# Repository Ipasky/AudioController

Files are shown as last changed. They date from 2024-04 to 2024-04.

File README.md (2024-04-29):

# Physical Audio Controller | Deej
This is my own 3D printing design that implements Deej software https://github.com/omriharel/deej able to control audio and mic devices on your computer in a physical way.

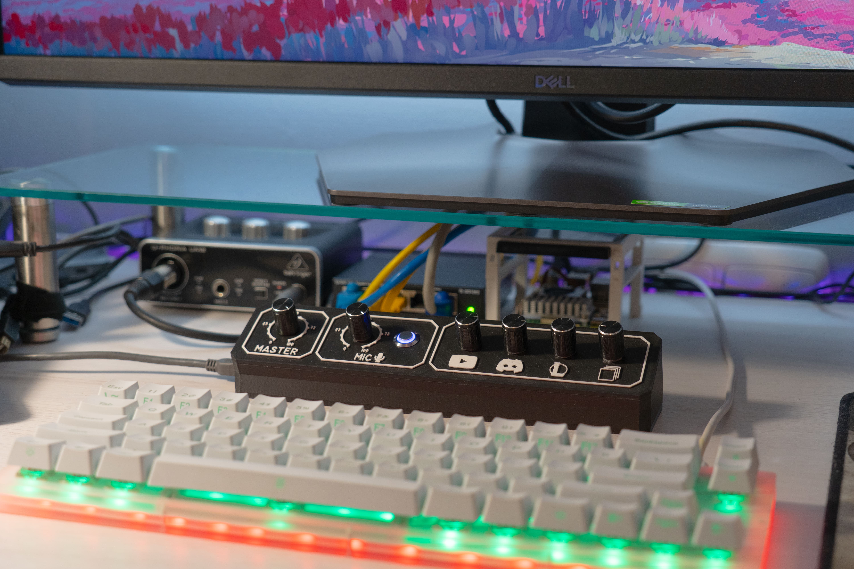
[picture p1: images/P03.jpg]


| | |
|:---:|:---:|
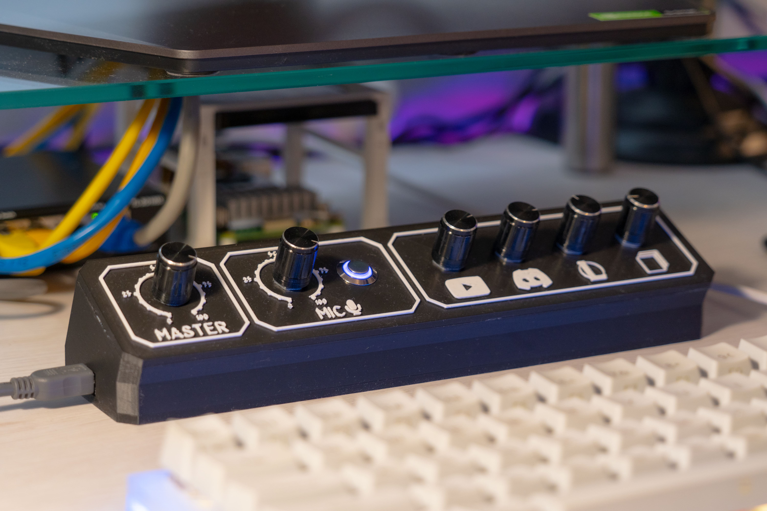
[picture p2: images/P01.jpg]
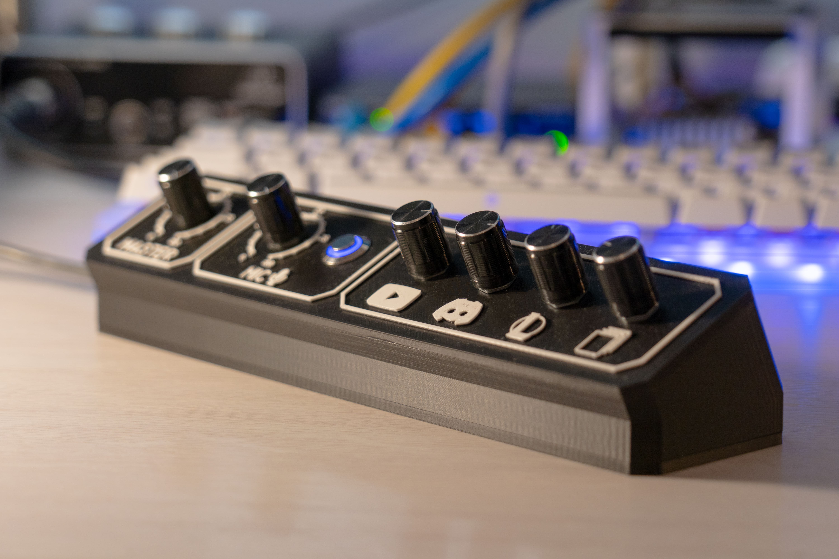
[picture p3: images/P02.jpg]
|  |  |

## Description
The build implements an Arduino Nano that carry the default code from Deej, in my case, with some modifications because I use a LED push button. You can found my modified code here: [Arduino Code](https://github.com/Ipasky/AudioControllerDeej/blob/main/DeejArduinoCodeMod.ino)

This additional code, in a nutshell, contains more analog inputs and one digital output (for the LED). Because the push button is not auto locking, that means the button is just pressed while you're pushing, in the Arduino code I need to implement a digital variable that controls the pulsation, writing in COM port and turning on and off the LED. I found the code from this page: https://roboticsbackend.com/arduino-turn-led-on-and-off-with-button/

I let here a schematic about the wiring, be aware that in this pic the Arduino board is not a Nano ones, for that reason it doesn't have 8 analogic ports.

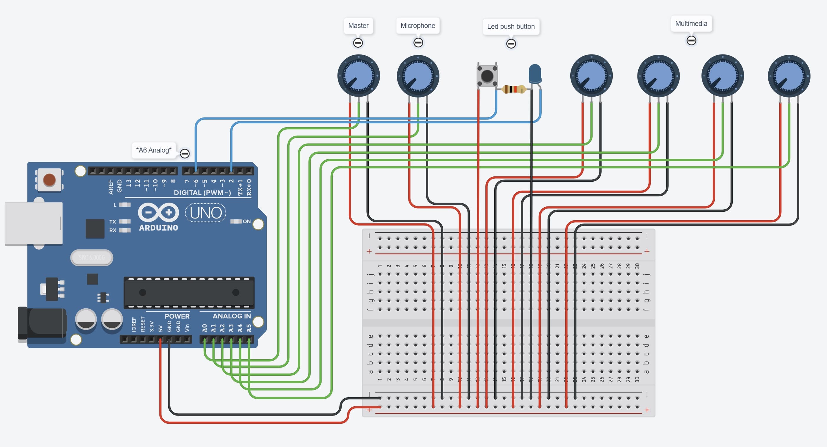
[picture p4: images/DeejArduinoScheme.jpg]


The push button that I use have 4 pins, two of them to the push button itself, and two more for the LED. In my case, I need to add a resistance trough negative LED pin to analog button pin. I really don't know if this wiring is the optimum, but it works for me.
| | |
|:---:|:---:|
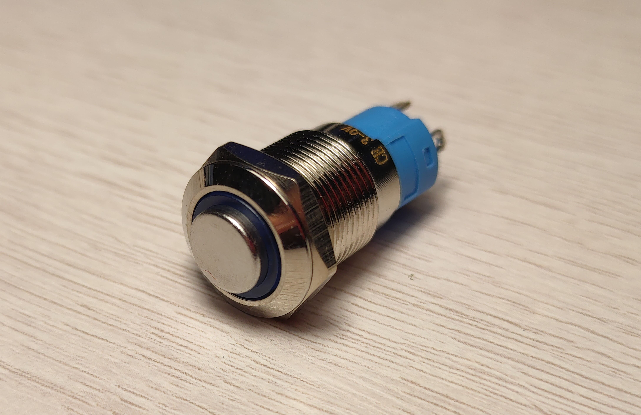
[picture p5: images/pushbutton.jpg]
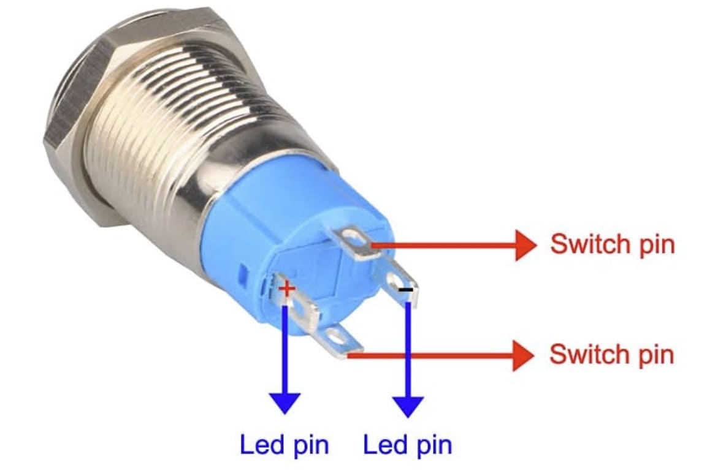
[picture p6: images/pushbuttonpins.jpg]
|  |  |

The final wiring looks like this:

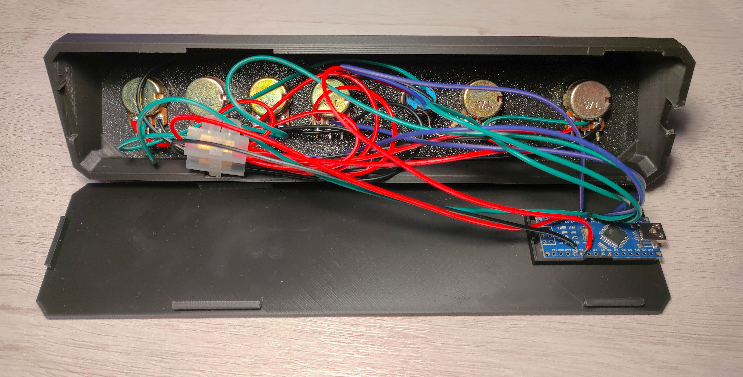
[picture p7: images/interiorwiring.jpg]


## Specs
- Dimensions: 220 x 60 x 44 mm
- Weight: 170g
- Material: black PLA & white PLA
- Printing time: 13h 44min

## Components
- [Arduino Nano](https://www.amazon.es/dp/B078S8BJ8T?psc=1&ref=ppx_yo2ov_dt_b_product_details) 
- [Potentiometers Kit](https://www.amazon.es/gp/product/B087Q9JVYD/ref=ppx_yo_dt_b_asin_title_o03_s01?ie=UTF8&psc=1)
- [Knobs](https://www.amazon.es/gp/product/B07DNBDFW8/ref=ppx_yo_dt_b_asin_title_o03_s00?ie=UTF8&psc=1)
- [Push Button](https://www.amazon.es/dp/B09Q8F5JR3?psc=1&ref=ppx_yo2ov_dt_b_product_details)
- Wiring cables
- Terminal block connector

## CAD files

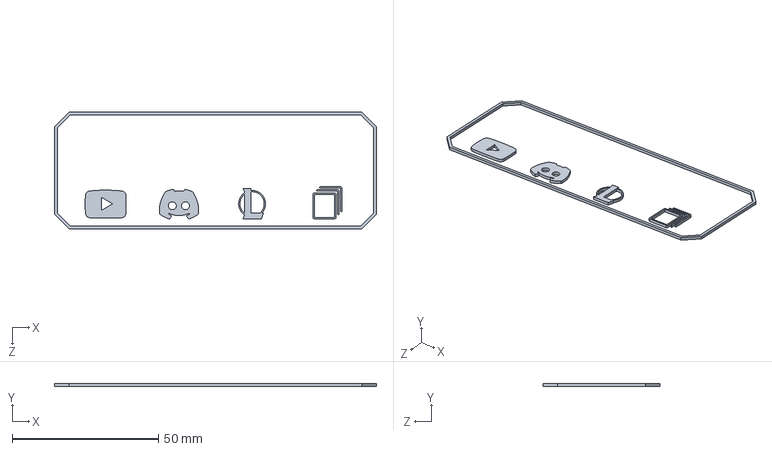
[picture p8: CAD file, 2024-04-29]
3D_Samples/SolidWorks/DeejMultiWhitePiece.SLDPRT
110.0 x 1.00 x 40.0 mm

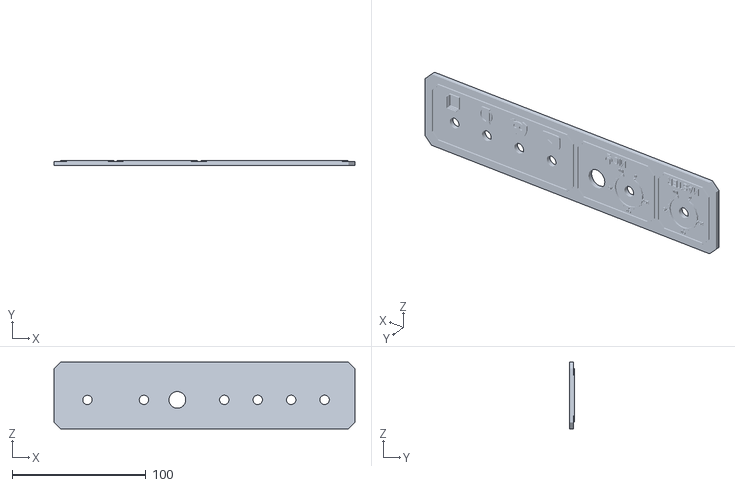
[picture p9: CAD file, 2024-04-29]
3D_Samples/STL/DeejTop.STL
225.0 x 4.00 x 50.0

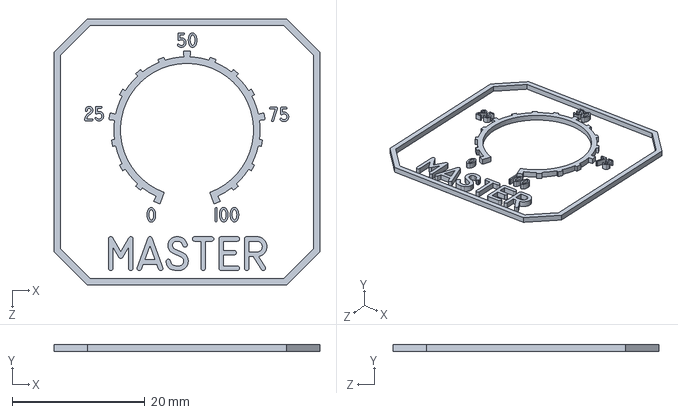
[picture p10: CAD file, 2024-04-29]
3D_Samples/SolidWorks/DeejMasterWhitePiece.SLDPRT
40.0 x 1.00 x 40.0 mm

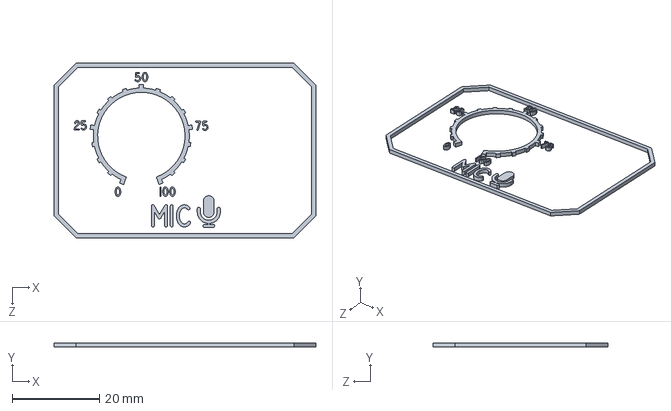
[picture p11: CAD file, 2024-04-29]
3D_Samples/SolidWorks/DeejMicWhitePiece.SLDPRT
60.0 x 1.00 x 40.0 mm

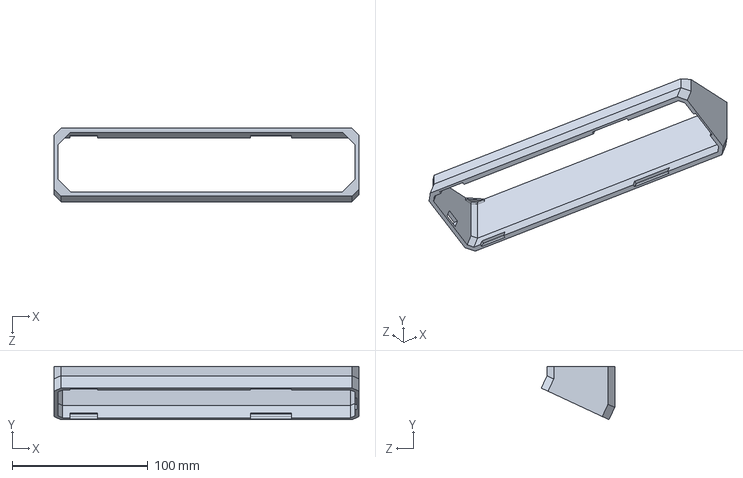
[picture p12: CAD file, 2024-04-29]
3D_Samples/SolidWorks/DeejCenter.SLDPRT
225.0 x 39.4 x 54.2 mm

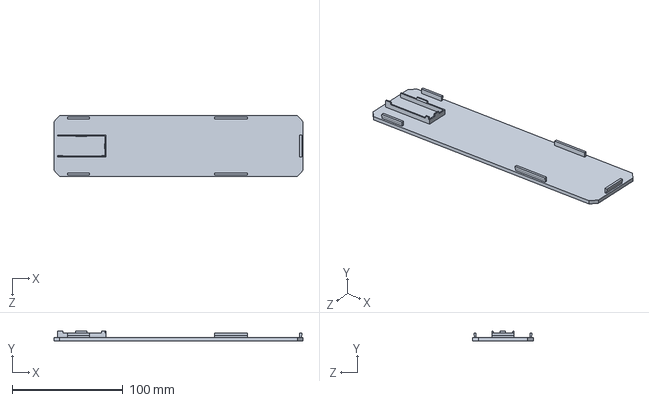
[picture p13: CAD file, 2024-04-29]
3D_Samples/SolidWorks/DeejBase.SLDPRT
225.0 x 9.00 x 55.2 mm

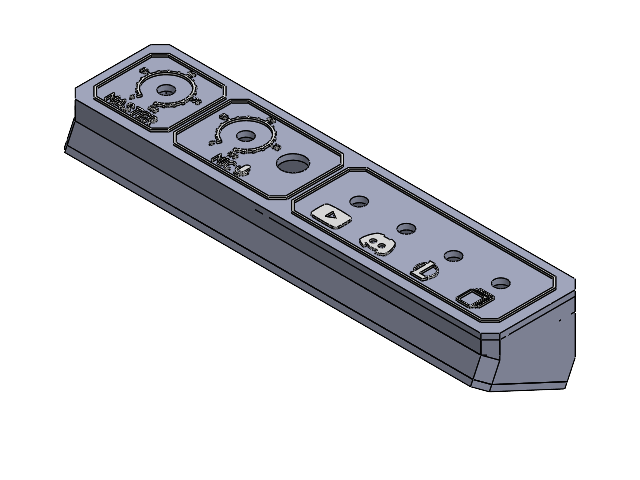
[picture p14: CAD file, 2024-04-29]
3D_Samples/SolidWorks/DeejAssembly.SLDASM
DeejMasterWhitePiece
DeejMicWhitePiece2
DeejMultiWhitePiece
DeejTopV2
DeejCenter
DeejBaseV2

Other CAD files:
3D_Samples/SolidWorks/DeejTopWhite.SLDPRT
3D_Samples/STL/DeejBase.STL
3D_Samples/STL/DeejCenter.STL

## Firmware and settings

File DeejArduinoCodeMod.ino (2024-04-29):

const int NUM_SLIDERS = 7;
const int analogInputs[NUM_SLIDERS] = {A0, A1, A2, A3, A4, A5, A6};
const int BUTTON_LED = 2;
byte lastButtonState = LOW;
byte ledState = LOW;

int analogSliderValues[NUM_SLIDERS];

unsigned long debounceDuration = 50; // millis
unsigned long lastTimeButtonStateChanged = 0;

void setup() { 
  for (int i = 0; i < NUM_SLIDERS; i++) {
    pinMode(analogInputs[i], INPUT);
  }
  pinMode(BUTTON_LED, OUTPUT);
  Serial.begin(9600);
}

void loop() {
  updateSliderValues();
  sendSliderValues(); // Actually send data (all the time)
  // printSliderValues(); // For debug
  delay(10);
}

void updateSliderValues() {
  for (int i = 0; i < NUM_SLIDERS; i++) {
     analogSliderValues[i] = analogRead(analogInputs[i]);
  }
}

void sendSliderValues() {
  String builtString = String("");

  if (millis() - lastTimeButtonStateChanged > debounceDuration) {
    byte buttonState = analogRead(analogInputs[6]);
    if (buttonState != lastButtonState) {
      lastTimeButtonStateChanged = millis();
      lastButtonState = buttonState;
      if (buttonState == LOW) {
        ledState = (ledState == HIGH) ? LOW: HIGH;
        digitalWrite(BUTTON_LED, ledState);
      }
    }
  }

  for (int i = 0; i < NUM_SLIDERS; i++) {
    if((i == 6) && (ledState == HIGH)){
      builtString += String("0");
    }
    else if((i == 6) && (ledState == LOW)){
      builtString += String("1023");
    }
    else{
      builtString += String((int)analogSliderValues[i]);
    }
    
    if (i < NUM_SLIDERS - 1) {
      builtString += String("|");
    }
  }

  Serial.println(builtString);
}

void printSliderValues() {
  for (int i = 0; i < NUM_SLIDERS; i++) {
    String printedString = String("Slider #") + String(i + 1) + String(": ") + String(analogSliderValues[i]) + String(" mV");
    Serial.write(printedString.c_str());

    if (i < NUM_SLIDERS - 1) {
      Serial.write(" | ");
    } else {
      Serial.write("\n");
    }
  }
}

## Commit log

2024-04-29 Add 3D samples
    [DeejBaseV2.SLDPRT, DeejBaseV2.STL, DeejCenter.SLDPRT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]
2024-04-29 arduino code
2024-04-29 add interior wiring
